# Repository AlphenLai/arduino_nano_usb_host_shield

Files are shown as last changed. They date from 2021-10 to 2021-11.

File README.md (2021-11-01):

# arduino_nano_usb_host_shield
An USB host shield for Arduino Nano, built from a mini USB host shield

This project creates an interface to combine easy accessed Arduino Nano and Arduino Mini USB Host Shield. This can be meaningless as USB Host Shield for Arduino Uno is everywhere on the market. If size doesn't matter, that would be a far easier option.

## Hardware

### BOM

| Reference | Quantity | Value | Footprint |
| --- | --- | --- | --- |
| A1 | 1 | Arduino_Nano | |
| D1 D2 D3 D4 | 4 | LED | LED_0603 |
| 5V_share | 1 | Conn_01x02_Male | Connector_PinHeader_2.54mm |
| Output | 1 | Conn_01x09_Male | Connector_PinHeader_2.54mm |
| Host_Shield | 2 | Conn_01x02_Male | Connector_PinHeader_2.54mm |
| Host_Shield | 2 | Conn_01x04_Male | Connector_PinHeader_2.54mm |
| Nano pin | 13 | Conn_01x13_Male | Connector_PinHeader_2.54mm |
| R1 R2 R3 R4 | 4 | 220 | R_0805 |
| R5 R6 R7 R8 | 4 | 10k | R_0805 |
| SW1 | 1 | SW_DIP_x04 | SW_DIP_SPSTx04_Slide |

### Preview

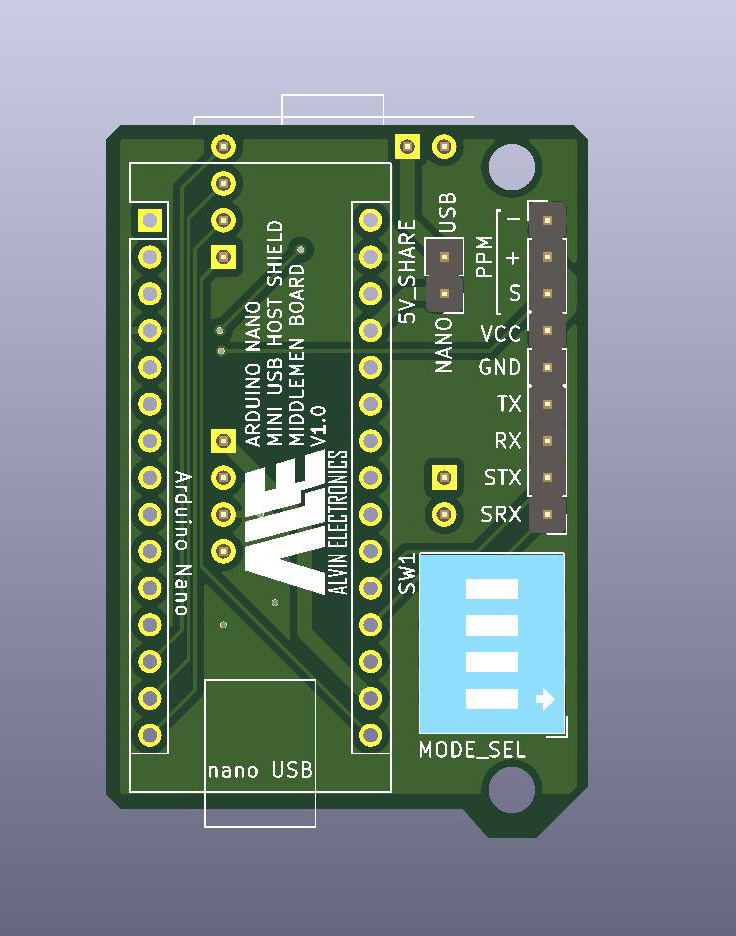
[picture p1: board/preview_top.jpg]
PCB preview


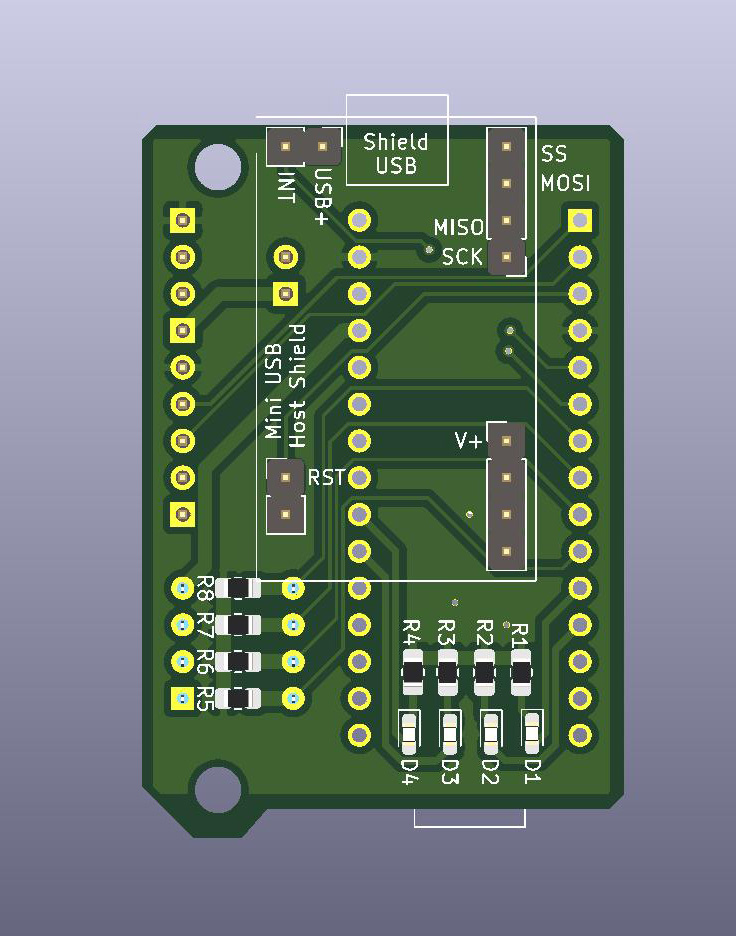
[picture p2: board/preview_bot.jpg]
PCB preview


### Pins

#### Assignment

| Pin  | Usage |
| ---- | --- |
| A0 | IO |
| A1 | IO |
| 0	 | Serial RX |
| 1 | Serial TX |
| A2 | PWM out |
| 4 | Switch 1  |
| 5 | Switch 2  |
| 6 | Switch 3  |
| 7 | Switch 4  |
| 8 | LED 1 |
| 9 | LED 2 |
| A2 | LED 3 |
| A3 | LED 4 |

There are 4 programmable LEDs and 4 switches on the board, which allows multiple purposes.

A Serial, a PWM pin, and 2 IO pins are routed to usable headers. PWM pins is for PPM output, and the IO pins are for software serial.

If you are happy to power everything with single source, put a jumper on the header below:

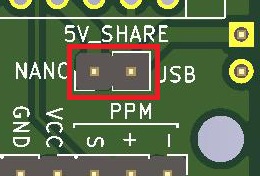
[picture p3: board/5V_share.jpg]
5V_share


Otherwise, use the headers to provide private power to Arduino Nano and USB device respectively.

#### Soldering Tips

The stock Arduino Mini USB Host Shield uses 3.3V from Arduino Mini to power up the USB device. Usually this is not enough. Clone boards removed a VBUS jumper so there is no voltage selection, cut the trace and use middleman board to supply 5V to USB device.

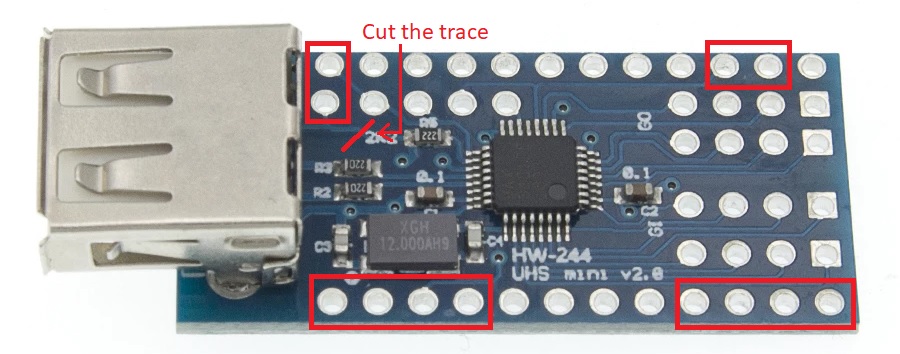
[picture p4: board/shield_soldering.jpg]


Solder headers to labeled pins.

Soldering both boards to the middleman board would cause huge pain if any repairing is needed later. Consider using socket or pogo pin for Arduino's side. Reference dimensions:

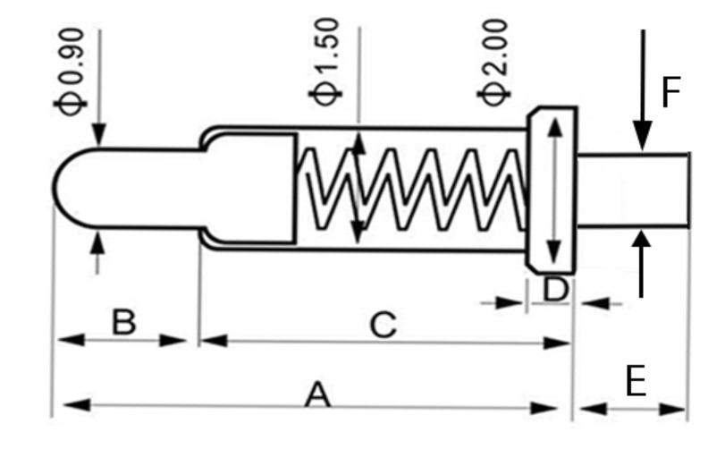
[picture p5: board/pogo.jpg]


with A=5, B=1.5, C=3.5, E=2, F=0.8, 13pin, plastic housing interval 2.54, width 2.55, height 2.5

#### Housing

The 3D printable housing is designed for pogo pins or headers. If you have the top headers on Arduino or using socket for connection, the housing will be too small.

There are some buckles to press the pogo pins continuously, as the screws are too far away to keep adding pressing, due to lack of space. Remove the buckles if you soldered everything together with headers.

## Software

Uses USB_Host_Shield_2.0 library by felis

https://github.com/felis/USB_Host_Shield_2.0

It should work on the Nano.

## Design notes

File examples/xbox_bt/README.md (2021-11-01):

## Library

The example program uses USB_Host_Shield_2.0 library by felis, and PPMEncoder library by schinken. Make sure you have them installed.

https://github.com/felis/USB_Host_Shield_2.0

https://github.com/schinken/PPMEncoder

## USB device

In the example, the xboxone controller with Bluetooth combability is used. Distinguish the correct controller:

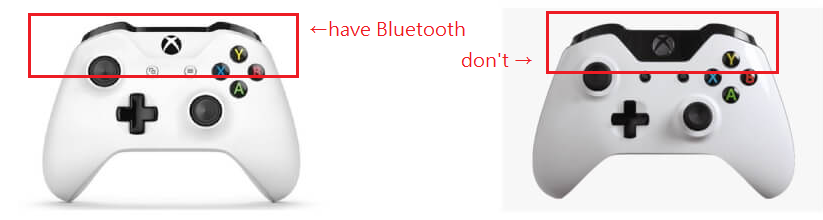
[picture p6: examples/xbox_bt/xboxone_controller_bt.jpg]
controller


Bluetooth dongle used:
UGREEN USB Bluetooth 4.0 Receiver Adapter

The dongle can be powered by Arduino with USB power. It won't be enough if you connect the controller via USB, wiredly. In that case, disconnect `5V_share` jumper and provide independent 5V to the device.

After xbox library initialized successfully, LED1 will turn on. Switch the controller to pairing mode before power on the board, or reset the Arduino after that.

## Serial mode

If you want to keep signals visible on pc serial, connect software serial pins to target device. However, this may reduce output speed as more operations are running.

Baud rate is adjustable but consider the maximum speed at the receiving side.

## PPM mode

To switch to PPM output mode, turn on the switch 1. However, this mode was never tested since I have lost my interest on the project, as I realized having only 8 channels is not going to work well with gaming controllers.

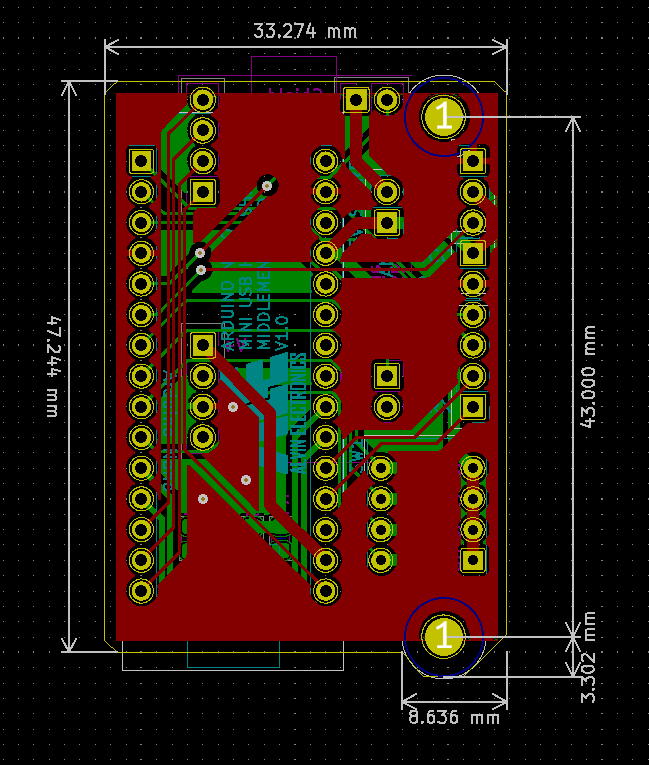
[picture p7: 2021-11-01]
board/board_dimension.jpg

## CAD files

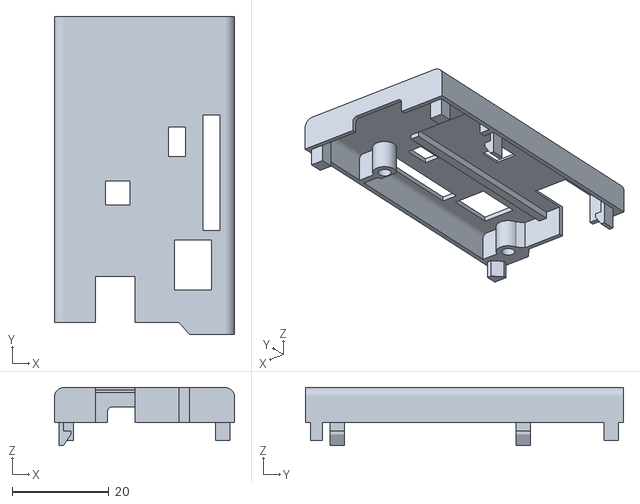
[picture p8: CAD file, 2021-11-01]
3D_printed_housing/chassis_top.STL
37.3 x 65.7 x 12.0

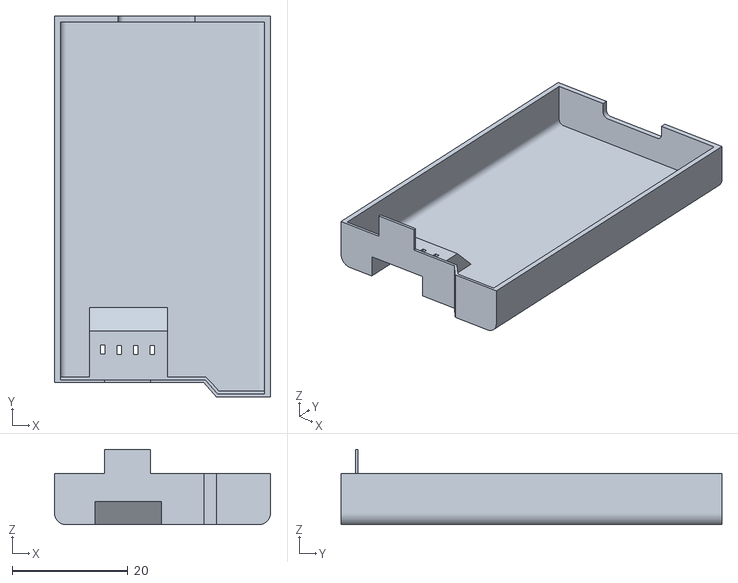
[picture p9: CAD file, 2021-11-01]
3D_printed_housing/chassis_bot.STL
37.3 x 65.7 x 13.0

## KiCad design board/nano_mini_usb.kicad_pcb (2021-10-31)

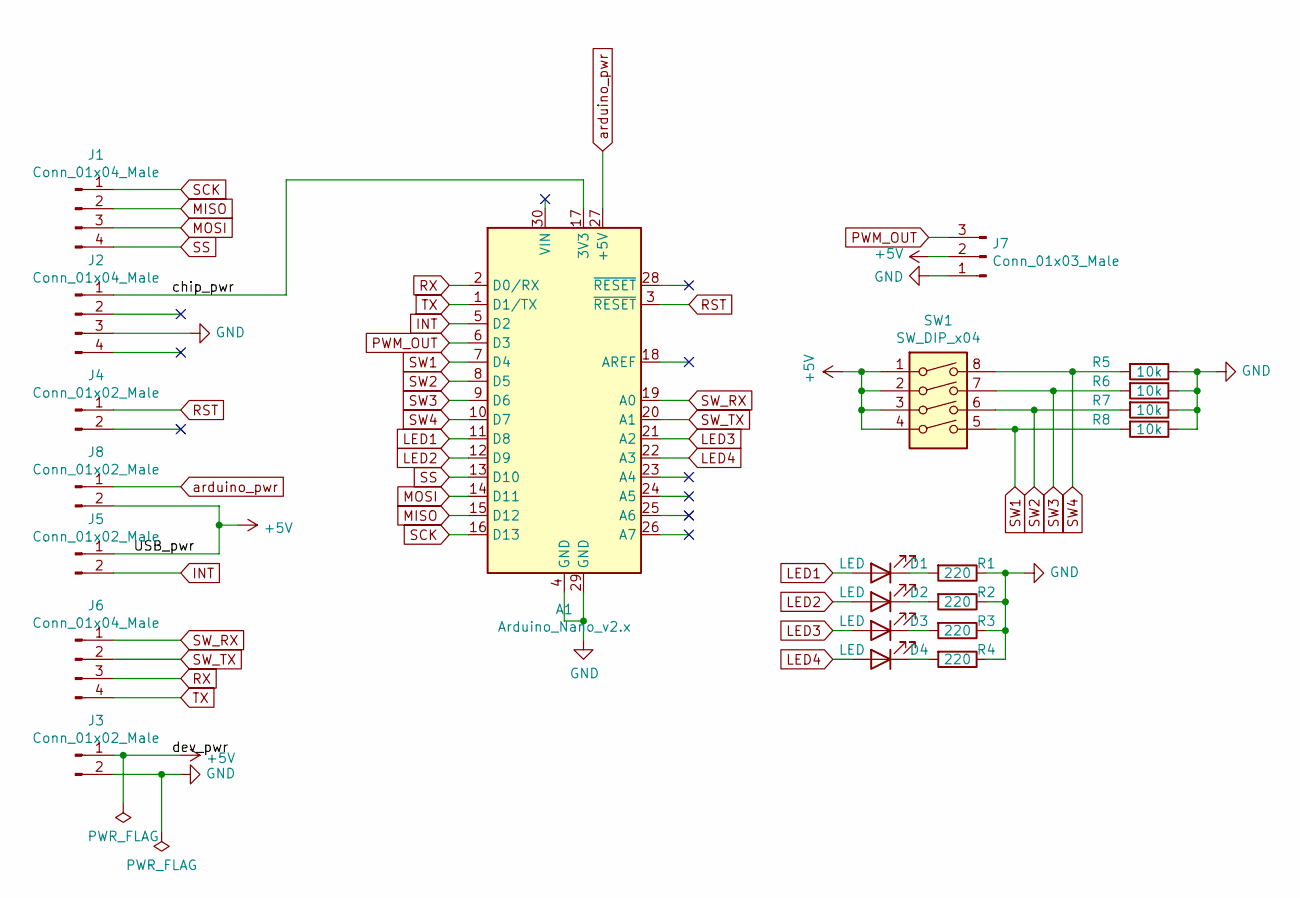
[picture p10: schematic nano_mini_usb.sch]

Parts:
A1: Arduino_Nano_v2.x; Arduino_Nano
D1, D2, D3, D4: LED; LED_0603_1608Metric_Pad1.05x0.95mm_HandSolder
J1, J2, J6: Conn_01x04_Male; PinHeader_1x04_P2.54mm_Vertical
J3, J4, J5, J8: Conn_01x02_Male; PinHeader_1x02_P2.54mm_Vertical
J7: Conn_01x03_Male; PinHeader_1x03_P2.54mm_Vertical
R1, R2, R3, R4: 220; R_0805_2012Metric_Pad1.20x1.40mm_HandSolder
R5, R6, R7, R8: 10k; R_0805_2012Metric_Pad1.20x1.40mm_HandSolder
SW1: SW_DIP_x04; SW_DIP_SPSTx04_Slide_9.78x12.34mm_W7.62mm_P2.54mm

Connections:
+5V: J3.1, J5.1, J7.2, J8.2, SW1.1, SW1.2, SW1.3, SW1.4
/chip_pwr: A1.17 (3V3), J2.1
GND: A1.4 (GND), A1.29 (GND), J2.3, J3.2, J7.1, R1.1, R2.1, R3.1, R4.1, R5.1, R6.1, R7.1, R8.1
INT: A1.5 (D2), J5.2
LED1: A1.11 (D8), D1.2 (A)
LED2: A1.12 (D9), D2.2 (A)
LED3: A1.21 (A2), D3.2 (A)
LED4: A1.22 (A3), D4.2 (A)
MISO: A1.15 (D12), J1.2
MOSI: A1.14 (D11), J1.3
unnamed: D1.1 (K), R1.2
unnamed: D2.1 (K), R2.2
unnamed: D3.1 (K), R3.2
unnamed: D4.1 (K), R4.2
PWM_OUT: A1.6 (D3), J7.3
RST: A1.3 (~RESET), J4.1
RX: A1.2 (D0/RX), J6.3
SCK: A1.16 (D13), J1.1
SS: A1.13 (D10), J1.4
SW1: A1.7 (D4), R8.2, SW1.5
SW2: A1.8 (D5), R7.2, SW1.6
SW3: A1.9 (D6), R6.2, SW1.7
SW4: A1.10 (D7), R5.2, SW1.8
SW_RX: A1.19 (A0), J6.1
SW_TX: A1.20 (A1), J6.2
TX: A1.1 (D1/TX), J6.4
arduino_pwr: A1.27 (+5V), J8.1

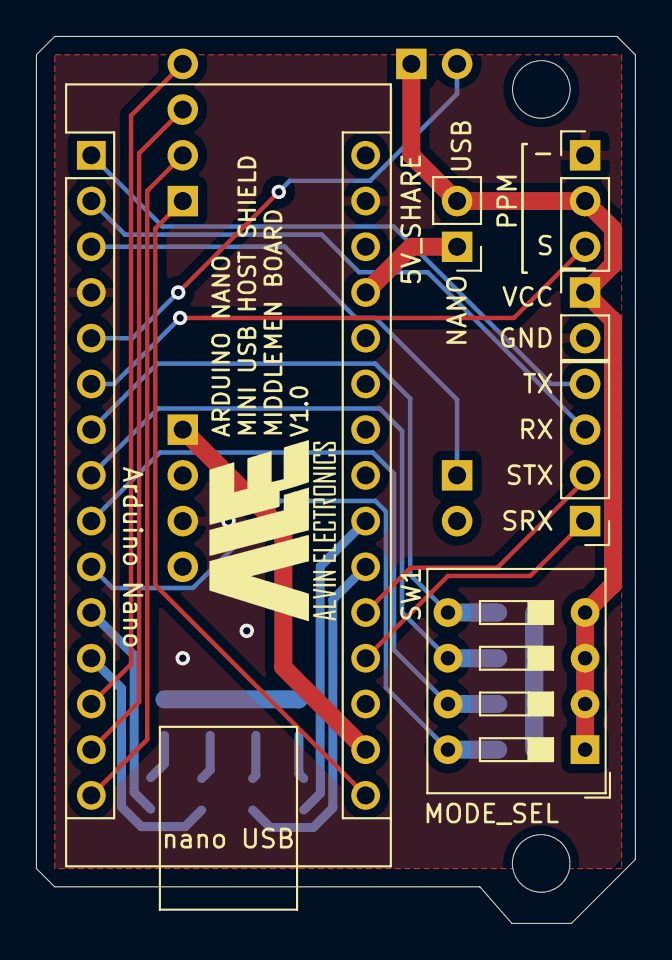
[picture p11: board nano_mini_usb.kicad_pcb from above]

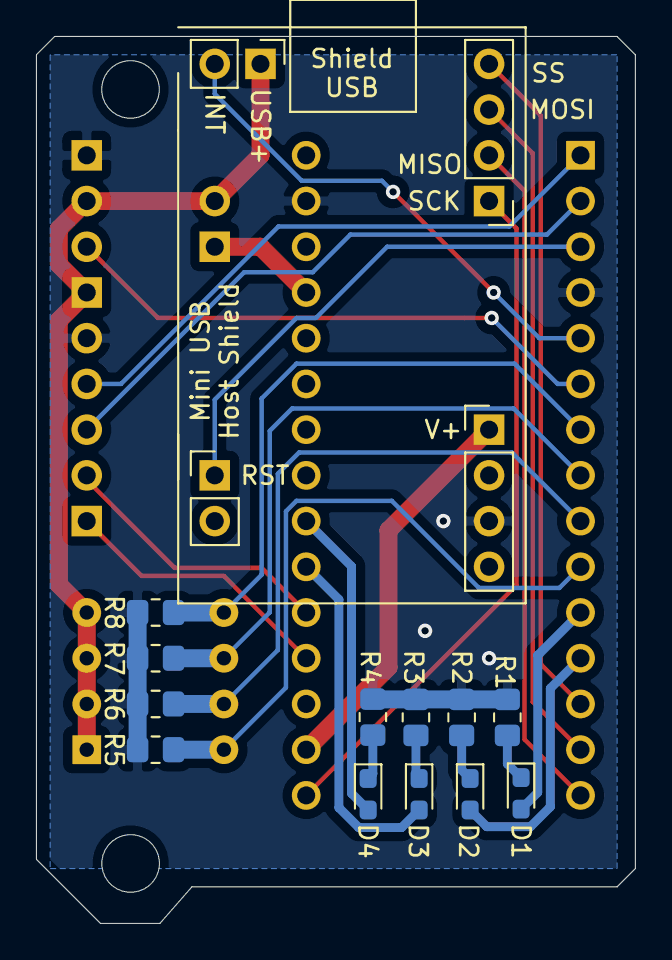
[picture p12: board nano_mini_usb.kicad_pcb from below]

Board: 2 copper layers, 33.3 x 49.3 mm, 22 parts (16 on the bottom side), 27 nets.

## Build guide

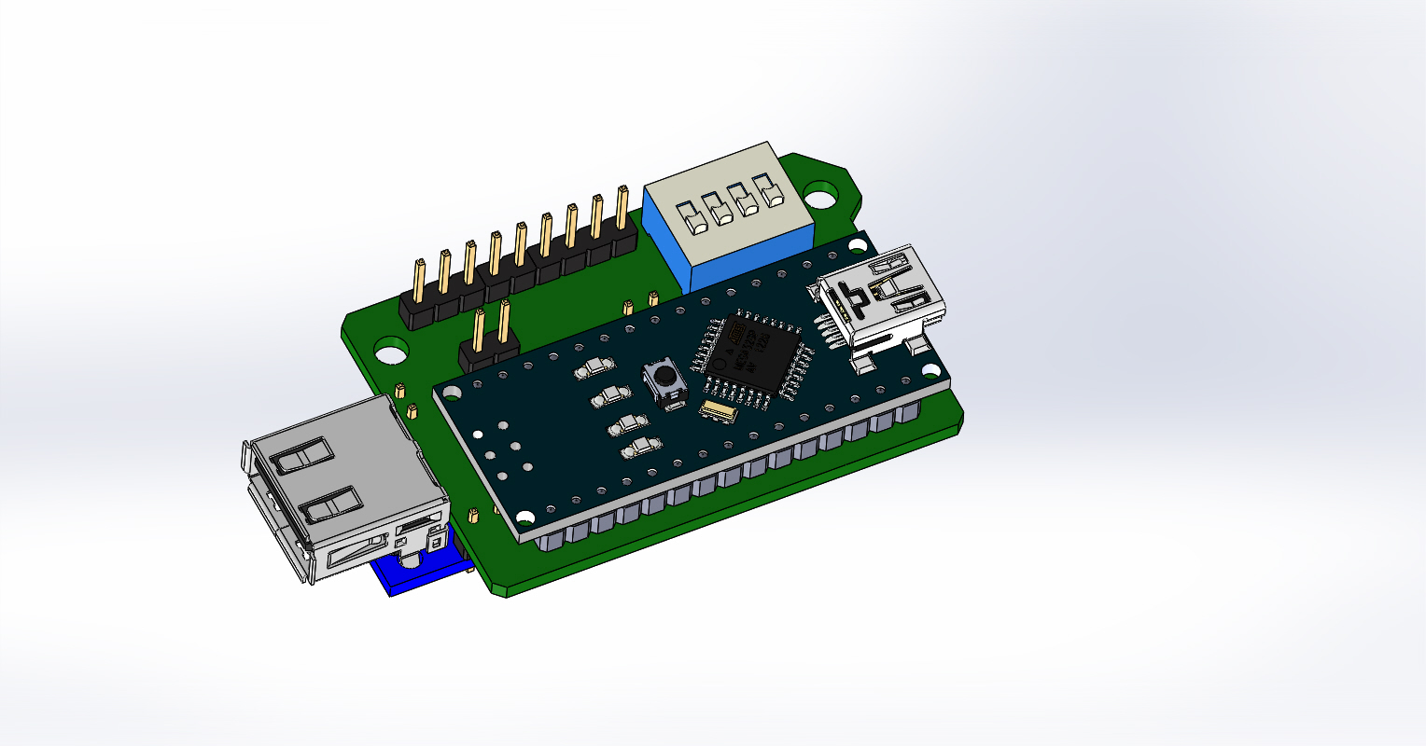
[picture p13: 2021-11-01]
board/assemble.JPG

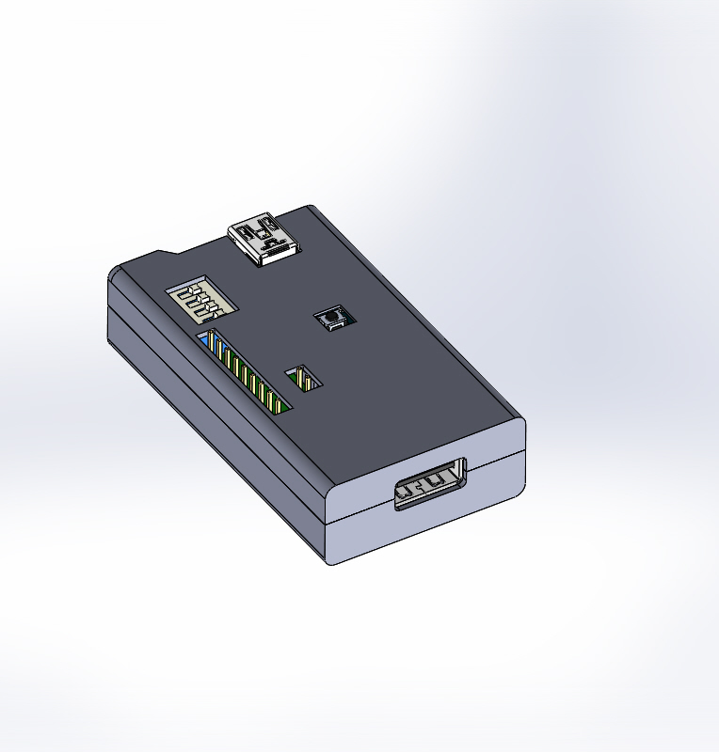
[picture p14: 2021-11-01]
3D_printed_housing/preview2.JPG

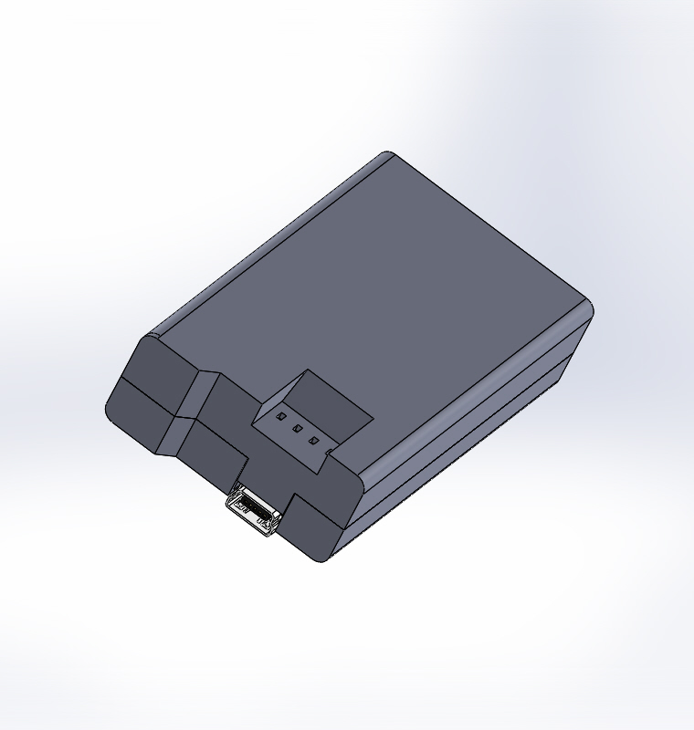
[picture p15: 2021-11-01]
3D_printed_housing/preview1.JPG

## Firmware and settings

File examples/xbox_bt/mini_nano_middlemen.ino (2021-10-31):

#include <XBOXONESBT.h>
#include <usbhub.h>
// Satisfy the IDE, which needs to see the include statment in the ino too.
#ifdef dobogusinclude
#include <spi4teensy3.h>
#endif
#include <SPI.h>
#include <SoftwareSerial.h>
#include "PPMEncoder.h"

#define DEBUG 1
#if DEBUG == 1
#define debug(x) Serial.print(x)
#define debugln(x) Serial.println(x)
#else
#define debug(x)
#define debugln(x)
#endif

//pin assignments
#define SW_RX A0
#define SW_TX A1
#define PPM   3
#define SW1   4
#define SW2   5
#define SW3   6
#define SW4   7
#define LED_1 8
#define LED_2 9
#define LED_3 A2
#define LED_4 A3

//PPM params
#define PPM_min 1100
#define PPM_max 1900

USB Usb;
BTD Btd(&Usb);
XBOXONESBT Xbox(&Btd, PAIR);
SoftwareSerial swSerial(14, 15); // RX, TX (A0, A1)

bool LED_state[4] = {0, 0, 0, 0};

//serial params
float stick_max = 32767.0;
float stick_min = 7500.0;
float ana_max = 1023;
uint8_t float_digit = 3;

String joystick_check_serial();
uint16_t button_check_serial();
void joystick_check_ppm();
void button_check_ppm();

void setup() {  
  pinMode(SW1, INPUT);      //serial 0 PPM 1
  pinMode(SW2, INPUT);
  pinMode(SW3, INPUT);
  pinMode(SW4, INPUT);
  pinMode(LED_1, OUTPUT);   //USB ok 1 fail 0
  pinMode(LED_2, OUTPUT);   //serial 0 PPM 1
  pinMode(LED_3, OUTPUT);   //output 1 no output 0
  pinMode(LED_4, OUTPUT);

  //init
  digitalWrite(LED_1, LOW);
  digitalWrite(LED_2, digitalRead(SW1));
  digitalWrite(LED_3, LOW);
  digitalWrite(LED_4, LOW);

  LED_state[1] = digitalRead(SW1);

  if (digitalRead(SW1)==1)
    ppmEncoder.begin(PPM);
  
  Serial.begin(57600);
  swSerial.begin(57600);
#if !defined(__MIPSEL__)
  while (!Serial); // Wait for serial port to connect - used on Leonardo, Teensy and other boards with built-in USB CDC serial connection
#endif
  while (!Serial); // Wait for serial port to connect - used on Leonardo, Teensy and other boards with built-in USB CDC serial connection
  debugln(digitalRead(SW1));
  if (Usb.Init() == -1) {
    debug(F("\r\nInit Failed"));
    while (1); //halt
  }
  debug(F("\r\nXbox One S Bluetooth Library Started"));
  digitalWrite(LED_1, HIGH);
  LED_state[0] = 1;
}
void loop() {
  Usb.Task();
  if (Xbox.connected()) {
    //LeftHatX, LeftHatY, RightHatX, RightHatY, L2, R2, L1, R1, L3, R3, UP, DOWN, LEFT, RIGHT, A, B, X, Y, START, BACK, XBOX, SYNC
    digitalWrite(LED_3, HIGH);
    LED_state[1] = 1;
    if (digitalRead(SW1) == 0) {  //serial mode
      String msg = joystick_check_serial();
      msg += String((long)button_check_serial());

      swSerial.println(msg);
      Serial.println(msg);
    }
  	else {	//PPM mode
      joystick_check_ppm();
      button_check_ppm();
	  }
  }
  else {  //xbox connection fail
    if (digitalRead(SW1) == 0) {  //serial mode
      String err_msg = "0.000 0.000 0.000 0.000 0.000 0.000 0";
      delay(50);
      swSerial.println(err_msg);
      Serial.println(err_msg);
    }
    else { //PPM mode
      delay(50);
    }
  }
}

String joystick_check_serial() {
  String msg = "";
  if(Xbox.getAnalogHat(LeftHatX) >= stick_min) {
    msg += String(((float(Xbox.getAnalogHat(LeftHatX)) - stick_min)/(stick_max-stick_min)), float_digit);
  }
  else if(Xbox.getAnalogHat(LeftHatX) <= -stick_min) {
    msg += String(((float(Xbox.getAnalogHat(LeftHatX)) + stick_min)/(stick_max-stick_min)), float_digit);
  }
  else 
    msg += "0.000";      
  msg += " ";
  
  if(Xbox.getAnalogHat(LeftHatY) >= stick_min) {
    msg += String(-((float(Xbox.getAnalogHat(LeftHatY)) - stick_min)/(stick_max-stick_min)), float_digit);
  }
  else if(Xbox.getAnalogHat(LeftHatY) <= -stick_min) {
    msg += String(-((float(Xbox.getAnalogHat(LeftHatY)) + stick_min)/(stick_max-stick_min)), float_digit);
  }
  else 
    msg += "0.000";    
  msg += " ";
  
  if(Xbox.getAnalogHat(RightHatX) >= stick_min) {
    msg += String(((float(Xbox.getAnalogHat(RightHatX)) - stick_min)/(stick_max-stick_min)), float_digit);
  }
  else if(Xbox.getAnalogHat(RightHatX) <= -stick_min) {
    msg += String(((float(Xbox.getAnalogHat(RightHatX)) + stick_min)/(stick_max-stick_min)), float_digit);
  }
  else 
    msg += "0.000";    
  msg += " ";
  
  if(Xbox.getAnalogHat(RightHatY) >= stick_min) {
    msg += String(-((float(Xbox.getAnalogHat(RightHatY)) - stick_min)/(stick_max-stick_min)), float_digit);
  }
  else if(Xbox.getAnalogHat(RightHatY) <= -stick_min) {
    msg += String(-((float(Xbox.getAnalogHat(RightHatY)) + stick_min)/(stick_max-stick_min)), float_digit);
  }
  else 
    msg += "0.000";    
  msg += " ";
  
  if (Xbox.getButtonPress(LT) > 0)
    msg += String((float(Xbox.getButtonPress(LT))/ana_max), float_digit);
  else
    msg += "0.000";      
  msg += " ";
  
  if (Xbox.getButtonPress(RT) > 0)
    msg += String((float(Xbox.getButtonPress(RT))/ana_max), float_digit);
  else
    msg += "0.000";    
  msg += " ";

  return msg;
}

uint16_t button_check_serial() {
  uint16_t button_array = 0;
  Xbox.getButtonPress(LB) ? button_array |= (1<<15) : button_array |= (0<<15);
  Xbox.getButtonPress(RB) ? button_array |= (1<<14) : button_array |= (0<<14);
  Xbox.getButtonClick(L3) ? button_array |= (1<<13) : button_array |= (0<<13);
  Xbox.getButtonClick(R3) ? button_array |= (1<<12) : button_array |= (0<<12);
  Xbox.getButtonPress(UP) ? button_array |= (1<<11) : button_array |= (0<<11);
  Xbox.getButtonPress(DOWN) ? button_array |= (1<<10) : button_array |= (0<<10);
  Xbox.getButtonPress(LEFT) ? button_array |= (1<<9) : button_array |= (0<<9);
  Xbox.getButtonPress(RIGHT) ? button_array |= (1<<8) : button_array |= (0<<8);
  Xbox.getButtonPress(A) ? button_array |= (1<<7) : button_array |= (0<<7);
  Xbox.getButtonPress(B) ? button_array |= (1<<6) : button_array |= (0<<6);
  Xbox.getButtonPress(X) ? button_array |= (1<<5) : button_array |= (0<<5);
  Xbox.getButtonPress(Y) ? button_array |= (1<<4) : button_array |= (0<<4);
  Xbox.getButtonPress(VIEW) ? button_array |= (1<<3) : button_array |= (0<<3);
  Xbox.getButtonPress(MENU) ? button_array |= (1<<2) : button_array |= (0<<2);
  Xbox.getButtonPress(XBOX) ? button_array |= (1<<1) : button_array |= (0<<1);

  return button_array;
}

void joystick_check_ppm() {
  ppmEncoder.setChannel(0, ((float)Xbox.getAnalogHat(LeftHatX)-32768.0)/65535.0);
  ppmEncoder.setChannel(1, ((float)Xbox.getAnalogHat(LeftHatY)-32768.0)/65535.0);
  ppmEncoder.setChannel(2, ((float)Xbox.getAnalogHat(RightHatX)-32768.0)/65535.0);
  ppmEncoder.setChannel(3, ((float)Xbox.getAnalogHat(RightHatY)-32768.0)/65535.0);
  ppmEncoder.setChannel(4, ((float)Xbox.getButtonPress(LT)-32768.0)/65535.0);
  ppmEncoder.setChannel(5, ((float)Xbox.getButtonPress(RT)-32768.0)/65535.0);
}

void button_check_ppm() {
  ppmEncoder.setChannel(0, PPM_max);
  Xbox.getButtonPress(LB) ? ppmEncoder.setChannel(6, PPM_max) : ppmEncoder.setChannel(6, PPM_min);
  Xbox.getButtonPress(RB) ? ppmEncoder.setChannel(7, PPM_max) : ppmEncoder.setChannel(7, PPM_min);
}

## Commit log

2021-10-31 Initial Upload
    [nano_mini_usb.kicad_pcb, nano_mini_usb.sch]
2021-11-01 Upload 3D files
    [chassis_bot.STL, chassis_top.STL]
2021-11-01 Update PCB. Re-route switch power to Arduino +5V
    [nano_mini_usb.sch]
2021-11-01 Re-upload gerber
2021-11-01 Add dimension of the board
